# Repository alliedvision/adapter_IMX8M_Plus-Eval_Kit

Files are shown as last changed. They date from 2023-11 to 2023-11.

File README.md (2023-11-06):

# Allied Vision Adapter Board CSI-2 NXP i.MX 8M Plus Eval Kit

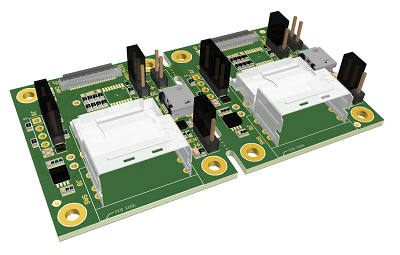
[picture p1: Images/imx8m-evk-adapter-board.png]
IMX8M-EVK Plus adapter board


This repository contains open hardware design files for an adapter board supporting the Allied Vision Alvium CSI-2 camera pinout to i.MX 8M Plus EVK. The board allows the user to interface with two Alvium MIPI CSI-2 compatible cameras over a Flexible Flat Cable (FFC) connector.

You can also purchase the adapter from [Allied Vision](https://www.alliedvision.com/en/products/accessories/interface-connections/#!?cameraInterfacefilter=10) or from our [distributors](https://www.alliedvision.com/en/avt-locations/avt-distributors/).

## Getting Started

These instructions will get you a copy of the design files to make your own adapter boards for development and testing purposes. 
The board can be produced and assembled using the provided design files. Please take a look at the mechanical layers for more information regarding the PCB stackup recommended for fabrication. 

More information is available on our website:

* [User Guide (PDF)](https://cdn.alliedvision.com/fileadmin/content/documents/products/accessories/embedded/user-guide/NXP-i.MX-8M-Plus_Adapter-Board.pdf)
* [Accessories webpage](https://www.alliedvision.com/en/products/accessories/interface-connections/#!?cameraInterfacefilter=10), 
* [Accessories download webpage](https://www.alliedvision.com/en/support/accessory-documentation/)
* [Alvium CSI-2 download webpage](https://www.alliedvision.com/en/support/technical-documentation/alvium-csi-2-documentation/) 

### Prerequisites

* A running installation of Altium.
* A PCB producer & PCBA manufacturer or some soldering skills.
* i.MX 8M Plus EVK board
* One or two supported MIPI CSI-2 FPC cables, Allied Vision product codes
 18947, 12316, 12317, 12318 
* [One or two Allied Vision Alvium CSI-2 cameras](https://www.alliedvision.com/en/products/embedded-vision-cameras.html)

### Installing

Open the *CSI2-IMX8M-EVK_Rev02.PrjPcb* project file in your Altium environment.

## Built With

[Altium Designer 22](https://www.altium.com/altium-designer/de)
 
## License

This project is licensed under the MIT License - see the [LICENSE](LICENSE) file for details

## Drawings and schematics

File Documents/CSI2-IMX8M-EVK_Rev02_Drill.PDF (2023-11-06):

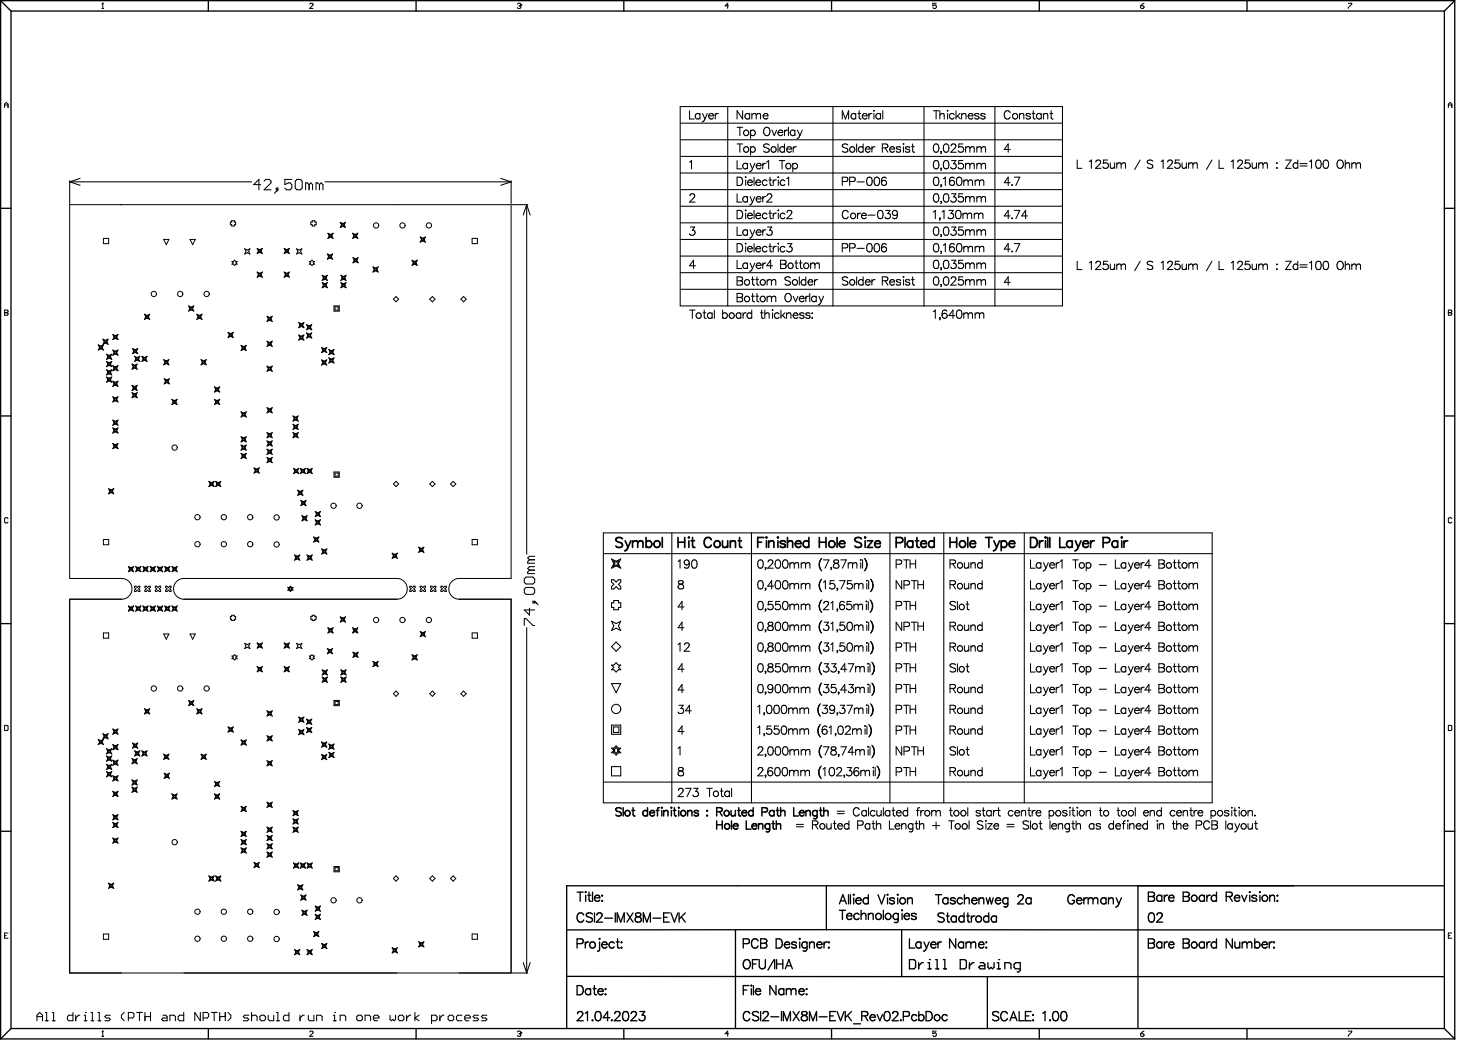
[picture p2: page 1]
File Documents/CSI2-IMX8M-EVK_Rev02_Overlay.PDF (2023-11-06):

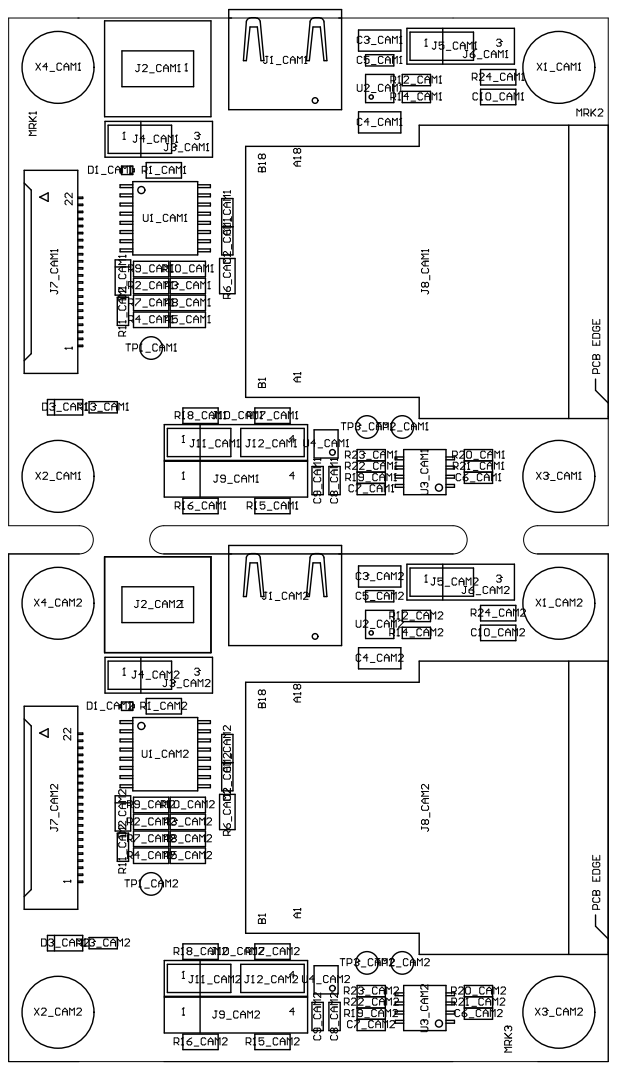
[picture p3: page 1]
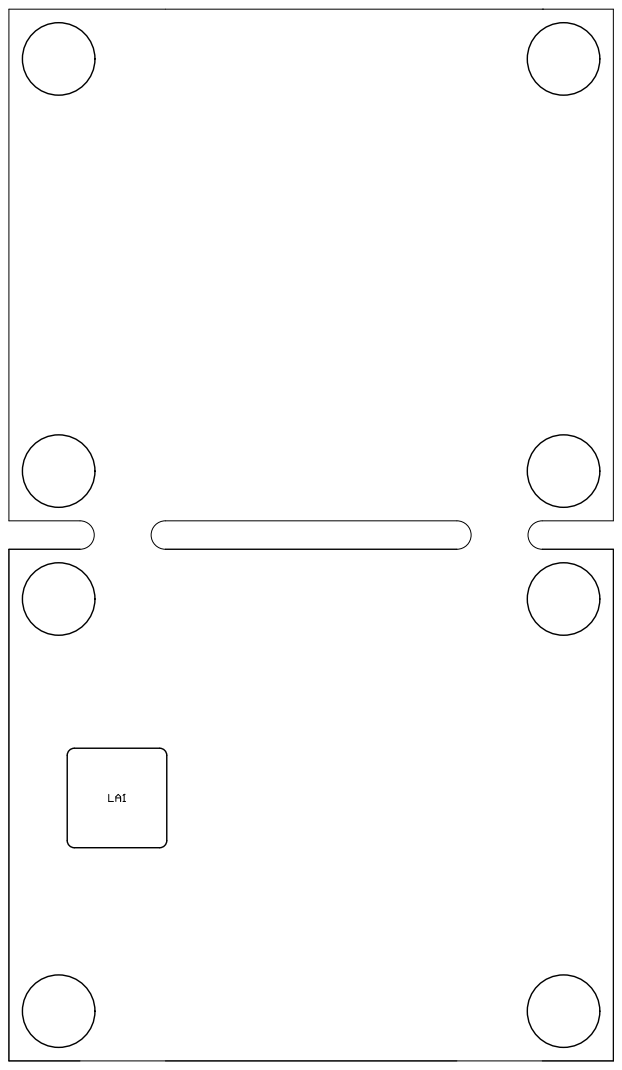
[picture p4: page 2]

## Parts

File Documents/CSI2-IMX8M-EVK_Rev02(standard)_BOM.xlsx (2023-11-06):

 | Bill of Materials | CSI2-IMX8M-EVK_Rev02
 | Project :
 | PCBA : |  | Revision : | 02
 | PCB : |  | Revision : | 02
 | Variant : | standard
 | Schematic : | CSI2-IMX8M-EVK_Rev02 | Schematic.pdf
 | Placement : | CSI2-IMX8M-EVK_Rev02 | Overlay.pdf
 | Report Date : | 21.04.2023 | 16:19
 | Alternative Parts :
Quantity | Designator | Comment | Footprint | Description | Manufacturer | Manufacturer Part Number | KHK Part Number
12 | C1_CAM1, C1_CAM2, C2_CAM1, C2_CAM2, C5_CAM1, C5_CAM2, C6_CAM1, C6_CAM2, C8_CAM1, C8_CAM2, C9_CAM1, C9_CAM2 | 100n | C-0402_0.55 | Capacitor Ceramic SMD/0402/16V/X7R/10% | several | several | K8340114
4 | C3_CAM1, C3_CAM2, C4_CAM1, C4_CAM2 | 10u | C-0805_1.4 | Capacitor Ceramic SMD/0805/16V/X5R/10% | several | several | K8340151
2 | C7_CAM1, C7_CAM2 | 100p | C-0402_0.55 | Capacitor Ceramic SMD/0402/50V/X7R/10% | several | several | K8340145
2 | C10_CAM1, C10_CAM2 | NL | C-0603_1.0 | Capacitor Ceramic SMD/0603/50V/X7R/10% | several | several
2 | D1_CAM1, D1_CAM2 | ESD9B5.0ST5G | D-SOD923 | DIODE TVS; 400W; 5.8-7.8V; BIDIRECT | ON Semiconductor | ESD9B5.0ST5G | 7250
2 | D3_CAM1, D3_CAM2 | GREEN | D-0603-LED | Chip LED green 430mcd | Würth | 150060GS75000 | 8172
2 | J1_CAM1, J1_CAM2 | USB 2.0 Typ B 90° | J-629105150521 | Micro USB 2.0 Typ B 90° | WE | 629 105 150 521 | 14360
2 | J2_CAM1, J2_CAM2 | CON1x2 | CON 1x2 RM2.54 | Header Vertical, 1x2 Pos, Pitch 2.54mm, Contact Length Mating 6.00mm, Contact Length Post 3.00mm, Insulation Height 2.54mm, Gold Plating | several | several | 15337
4 | J3_CAM1, J3_CAM2, J6_CAM1, J6_CAM2 | CON1x3 | CON 1x3 RM2.54 | Header Vertical, 1x3 Pos, Pitch 2.54mm, Contact Length Mating 6.00mm, Contact Length Post 3.00mm, Insulation Height 2.54mm, Gold Plating | several | several | 15338
8 | J4_CAM1, J4_CAM2, J5_CAM1, J5_CAM2, J11_CAM1, J11_CAM2, J12_CAM1, J12_CAM2 | Jumper | J-JUMPER-2.54 | CON/JUMPER/STC02SYAN; 2-pin; 2.54mm; 3A; FEMALE; VERTICAL; BLACK | several | several | 13444
2 | J7_CAM1, J7_CAM2 | CON FFC22_Inverted | J-FH55-22S-0.5SH - Inverted Pins | FFC Connector 0.5mm shielded | Hirose | FH55-22S-0.5SH | 10357
2 | J8_CAM1, J8_CAM2 | 75783-0132 | J-757830132 | 36pin MINI SAS iPass Receptacle 0.8mm pitch | Molex | 75783-0132 | 16136
2 | J10_CAM1, J10_CAM2 | CON1x4 | CON 1x4 RM2.54 | Header Vertical, 1x4 Pos, Pitch 2.54mm, Contact Length Mating 6.00mm, Contact Length Post 3.00mm, Insulation Height 2.54mm, Gold Plating | several | several | 15343
1 | LA1 | LABEL 7x7mm | PCB LABEL 7x7 | LABEL 7x7mm | several | several
3 | MRK1, MRK2, MRK3 | Marker Single Layer | PCB_Marker_Pad_top | Position Marker for PCBs
1 | PCB1 | LEO-CSI2-IMX8M-EVK_Rev02 |  | PCB ML04 | several | 14387-01 | 14387-01
14 | R1_CAM1, R1_CAM2, R3_CAM1, R3_CAM2, R6_CAM1, R6_CAM2, R9_CAM1, R9_CAM2, R15_CAM1, R15_CAM2, R16_CAM1, R16_CAM2, R24_CAM1, R24_CAM2 | 0R0 | R-0603_0.6 | Standard Resistor SMD/0603/1%/100mW/TK200 | several | several | K8250041
16 | R2_CAM1, R2_CAM2, R4_CAM1, R4_CAM2, R5_CAM1, R5_CAM2, R7_CAM1, R7_CAM2, R8_CAM1, R8_CAM2, R10_CAM1, R10_CAM2, R17_CAM1, R17_CAM2, R18_CAM1, R18_CAM2 | NL | R-0603_0.6 | Standard Resistor SMD/0603/1%/100mW/TK200
2 | R12_CAM1, R12_CAM2 | 270K | R-0402_0.4 | Standard Resistor SMD/0402/1%/63mW/TK100 | several | several | 3875
2 | R13_CAM1, R13_CAM2 | 3k3 | R-0402_0.4 | Standard Resistor SMD/0402/1%/63mW/TK100 | several | several | K8250347
2 | R14_CAM1, R14_CAM2 | 51k | R-0402_0.4 | Standard Resistor SMD/0402/1%/63mW/TK100 | several | several | K8250273
2 | R19_CAM1, R19_CAM2 | 200k | R-0402_0.4 | Standard Resistor SMD/0402/1%/63mW/TK100 | several | several | K8250280
8 | R20_CAM1, R20_CAM2, R21_CAM1, R21_CAM2, R22_CAM1, R22_CAM2, R23_CAM1, R23_CAM2 | 2k0 | R-0402_0.4 | Standard Resistor SMD/0402/1%/63mW/TK100 | several | several | K8250311
2 | U2_CAM1, U2_CAM2 | TPS25200DRVT | IC-DFN06_2.0x2.0x0.8 | IC/PWR/LOADSW;2V5-6V5;2A5;0R099/6-WDFN/2x2x0.8mm | Texas Instruments | TPS25200DRVT | 14277
2 | U3_CAM1, U3_CAM2 | PCA9306DCTR | IC-TSSOP8_3.15x4.25x1.3 | IC/LOGIC/LEVELSHIFTER;I2C;AUTO-DIR;1V2-5V/SSOP-8/4.25x3.15x1.3mm | TI | PCA9306DCTR | 9555
2 | U4_CAM1, U4_CAM2 | NTB0104GU12,115 | IC-XQFN12_1.7x2x0.5 | IC/LOGIC/Levelshifter;Auto-Dir;Bidirectional;Push-Pull;-40-+125°C/ | NXP | NTB0104GU12,115 | 14383
